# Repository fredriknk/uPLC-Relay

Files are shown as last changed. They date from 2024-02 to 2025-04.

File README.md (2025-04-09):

# μPLC-Relay
### Pcbway Sponsorship
Thanks so much to [PCBWay](https://www.pcbway.com/) who offered to assemble my first prototype batch of all three [uPLC modules](https://github.com/fredriknk/uPLC-stack). They deliver awesome quality as always, see the result for yourself below.
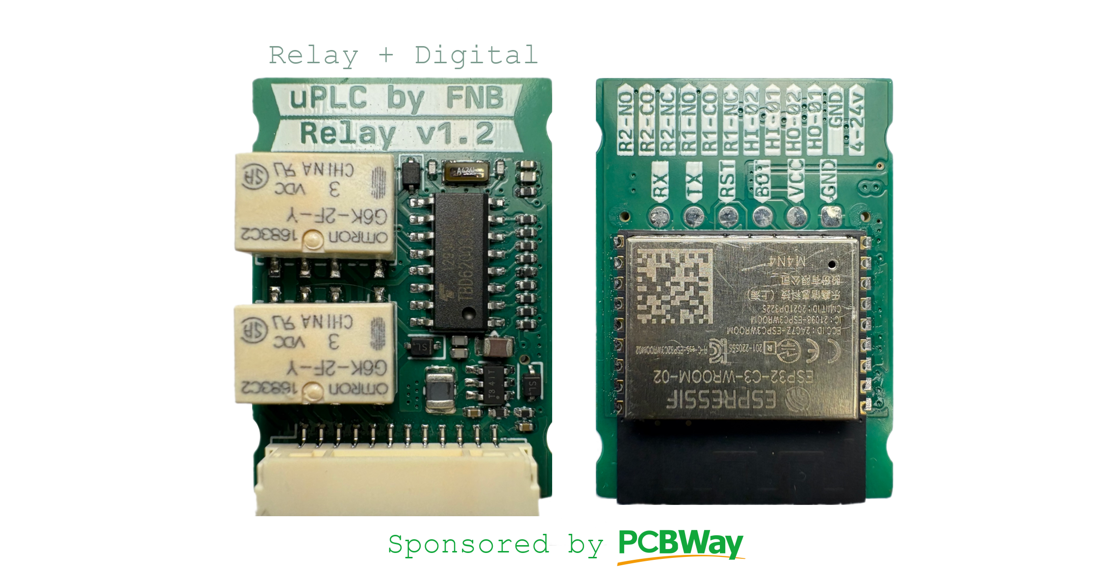
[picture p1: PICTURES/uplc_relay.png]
Front


 I now have two prototypes of the uPLC-Relay so ESP-Home integrations will come soon.

ESP micro PLC the size of a post stamp. he uPLC-relay version  has two small signal relay module utilizing an [ESP-32-C3](./DOCUMENTATION/esp-12f_product_specification_en.pdf) wifi, bluetooth module for communication and MCU, it has a 0-24V buck regulator, has two 2.5-25V inputs, two 25v, 100/50ma high speed open drain output through a [TBD062003](./DOCUMENTATION/2304140030_TOSHIBA-TBD62003AFWG_C114084.pdf) DMOS transistor array ic. And two relay outputs are capable of driving around 25V 500ma. 

Thanks to [u/PricelessToolkit/ESPClicker](https://github.com/PricelessToolkit/ESPClicker) for inspiration.

[Schematic](./DOCUMENTATION/_schematic.pdf)

[Assembly IBOM](https://htmlpreview.github.io/?https://raw.githubusercontent.com/fredriknk/uplc/main/DOCUMENTATION/ibom.html)

## Specifications
| **Parameter** | **Description** |
|---|---|
| _Input voltage_ | 3.8-24v |
| _Current_ | TBD Wifi: ##mA, Radio Off: ##mA, Deep sleep ##uA |  
| _Communication_ | 2.4ghz WIFI, Uart TTL |
| _Baudrate_ | 115200 |
| _PCB size_ | 22x31.1mm |
| _PCB info_ | 1.6mm FR4, HASL lead free, 4 layer |
| _Case size_ | XxXxXmm TBD |

## Connector

| **Label** | **GPIO**|**Description** |
|---|-----|---|
|_R2NO_ | GPIO5 | Relay 1 Normally Open |
|_R2CO_ | GPIO5  | Relay 1 COM |
|_R2NC_ | GPIO5 | Relay 1 Normally Closed |
|_R1NO_ | GPIO6 | Relay 1 Normally Open |
|_R1CO_ | GPIO6  | Relay 1 COM |
|_R1NC_ | GPIO6 | Relay 1 Normally Closed |
|_HI2_ | GPIO19 | 2.5-25v input |
|_HI1_ | GPIO18 | 2.5-25v input |
|_HO2_ | GPIO3 | 25v 50ma open drain output |
|_HO1_ | GPIO7 | 25v 100ma open drain output |
|_4-24V_ | 3V3 |4-24v |
|_GND_ | GND |  Ground  |

## PCB Pictures
PCB assembly by [PCBWay](https://www.pcbway.com/)
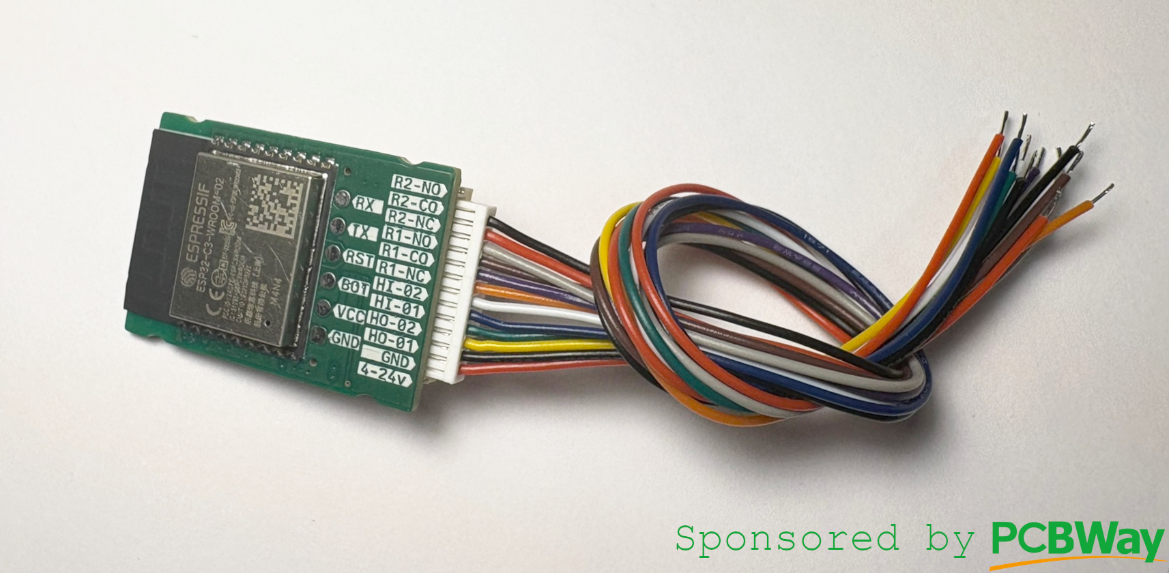
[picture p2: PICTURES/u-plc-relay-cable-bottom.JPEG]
Cable1

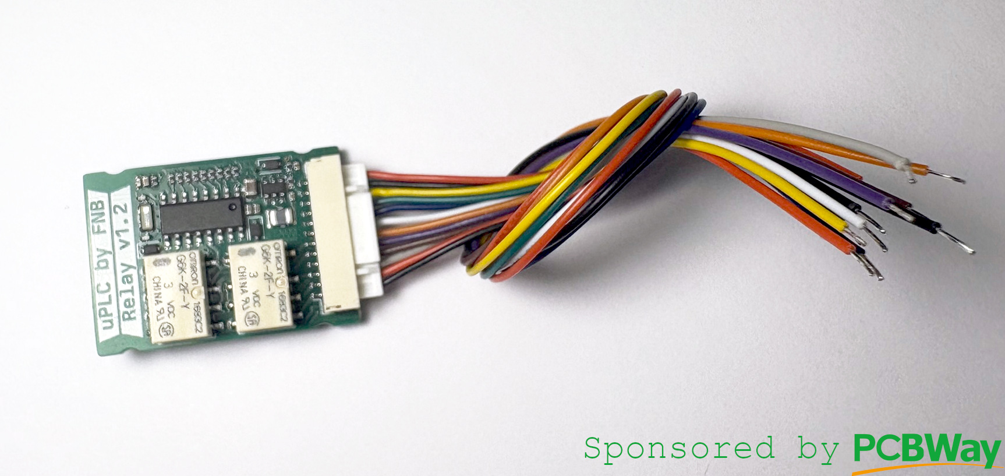
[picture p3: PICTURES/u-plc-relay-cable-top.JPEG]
Cable2

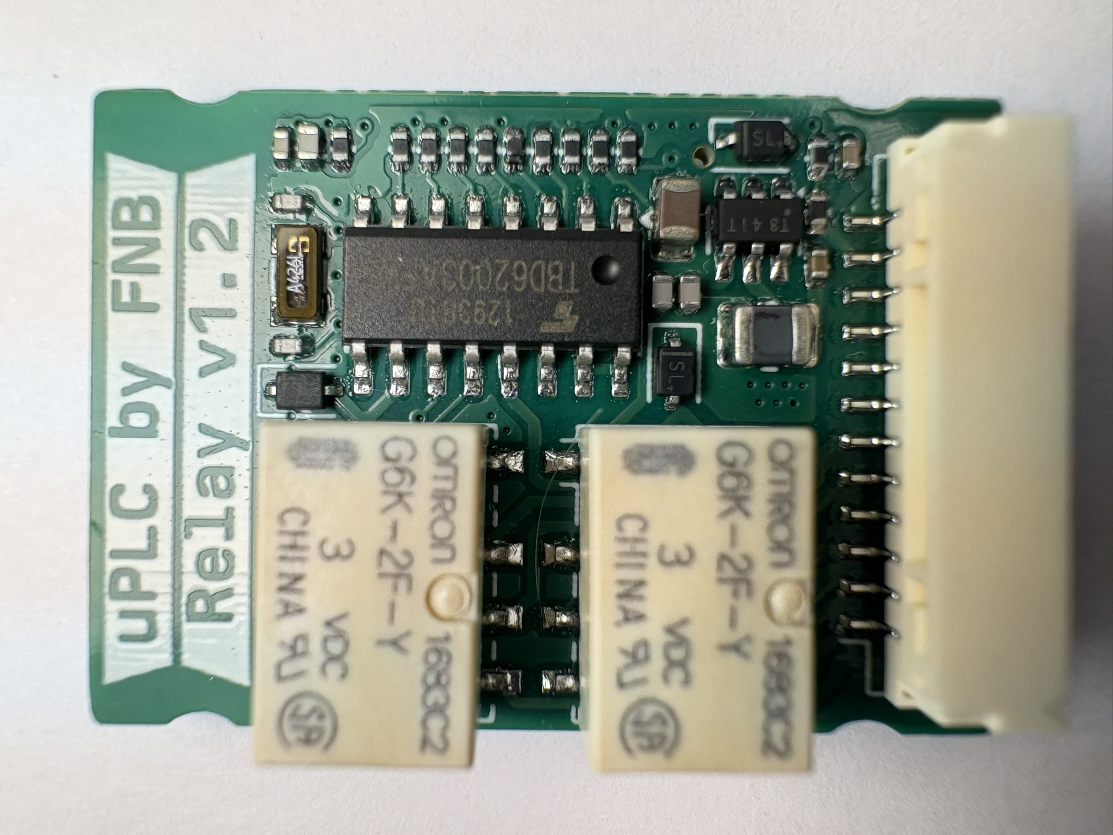
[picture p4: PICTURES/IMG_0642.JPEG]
Top

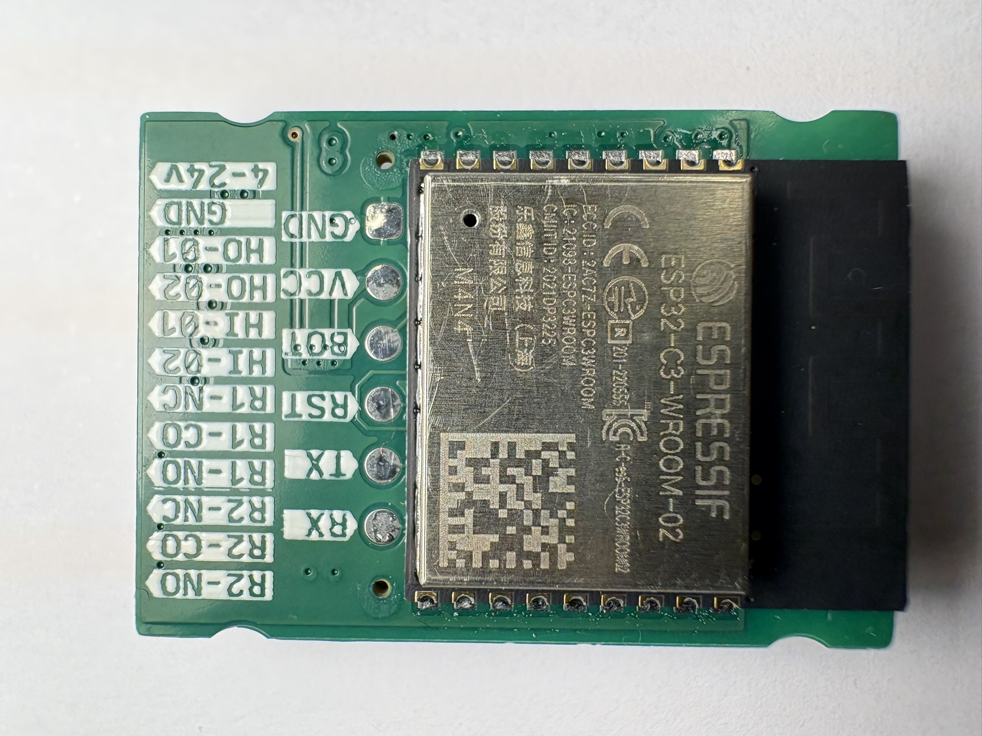
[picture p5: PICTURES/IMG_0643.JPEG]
Bottom


## Homeassistant Implementation
TODO

## FIRST PRODUCTION PROTOTYPE
TODO

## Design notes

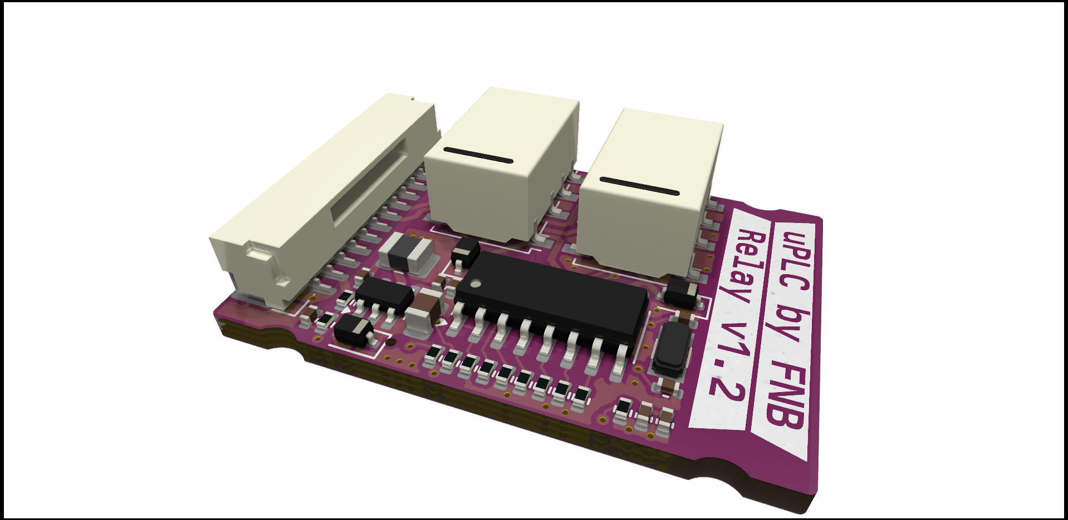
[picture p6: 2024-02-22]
PICTURES/TOP.PNG

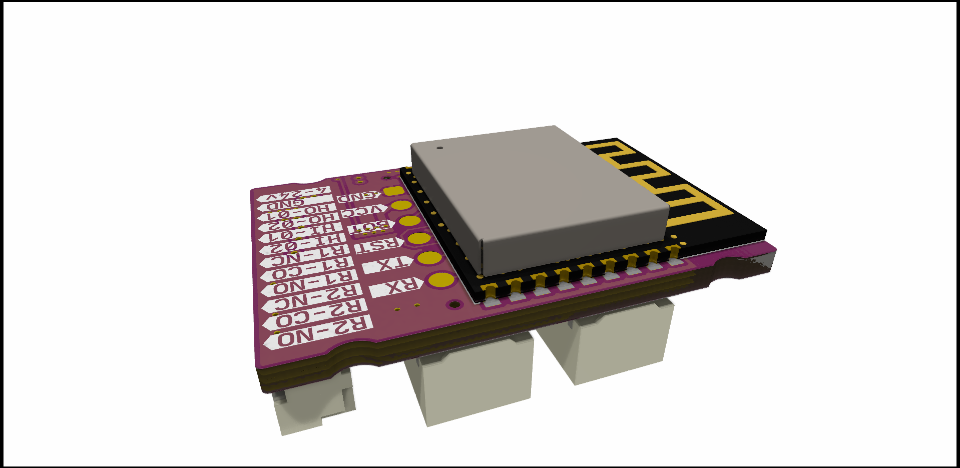
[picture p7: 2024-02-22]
PICTURES/BOTTOM.PNG

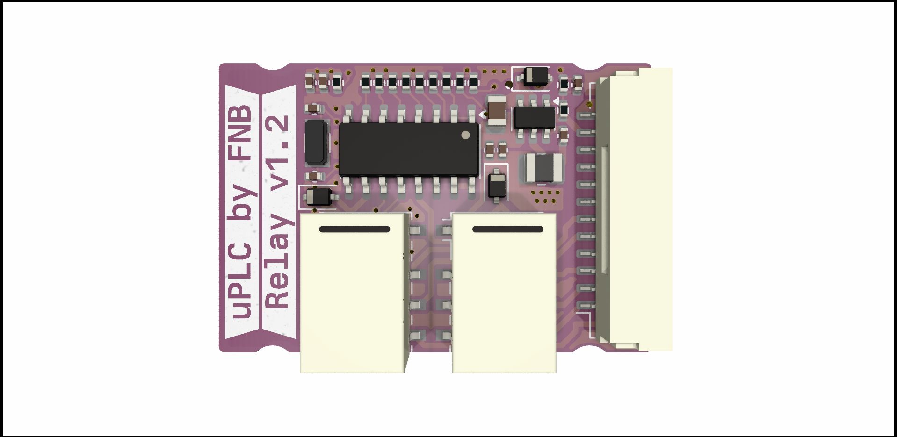
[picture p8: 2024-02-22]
PICTURES/OTOP.PNG

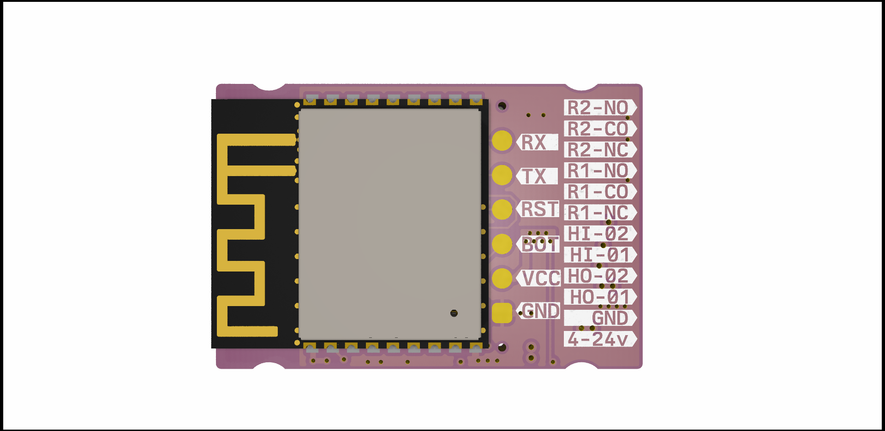
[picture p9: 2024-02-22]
PICTURES/OBOT.PNG

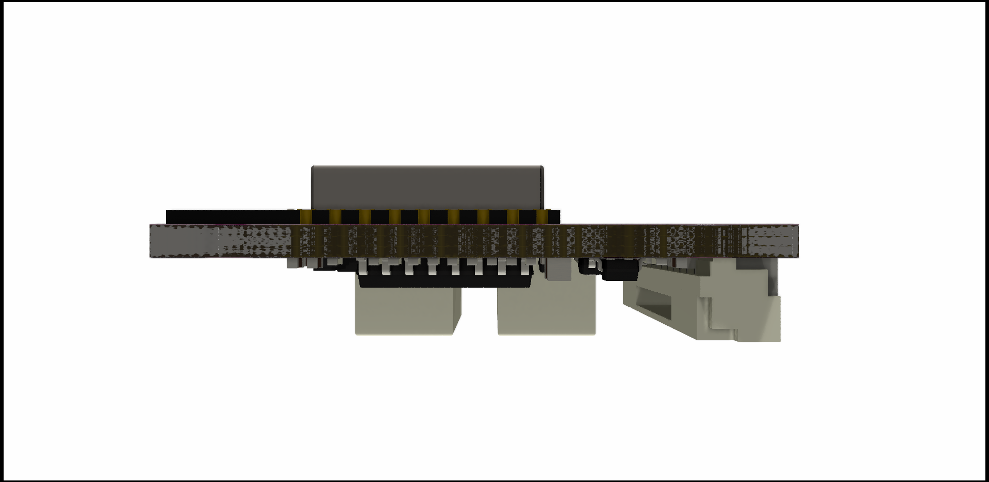
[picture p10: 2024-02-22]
PICTURES/OLEFT.png

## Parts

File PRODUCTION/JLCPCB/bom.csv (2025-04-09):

Designator | Footprint | Quantity | Value | LCSC Part #
C1, C4 | 0402 | 2 | 20pf | C1554
C11, C12, C8 | 0402 | 3 | 22uf | C415703
C2, C3, C9 | 0402 | 3 | 0.1uF | C77020
C5 | 0805 | 1 | 10uF | C162422
D1, D2, D4 | D_SOD-323 | 3 | 1N5819WS | C191023
J1 | TestPoint_Pad_1.0x1.0mm_6pad | 1 | Conn_01x06_Pin | DNP
J2 | JST_GH_SM12B-GHS-TB_1x12-1MP_P1.25mm_Horizontal | 1 | SM12B-GHS-TB(LF)(SN) | C265421
K1, K2 | Relay_DPDT_Omron_G6K-2F-Y | 2 | G6K-2F-Y | C93168
L1 | 1008 | 1 | 4.7uH | C82314
R1, R10, R11, R12, R2, R4, R5, R7, R8, R9 | 0402 | 10 | 10K | C25744
R14 | 0402 | 1 | 182k | C11481
R15 | 0402 | 1 | 62k | C137950
U1 | TSOT-23-6 | 1 | AP63201WU | C2071044
U2 | SOIC-16_3.9x9.9mm_P1.27mm | 1 | TBD62003AFWG | C114084
U3 | ESP32-C3-WROOM-02 | 1 | ESP32-C3-WROOM-02 | C2934560
Y1 | Crystal_SMD_3215-2Pin_3.2x1.5mm | 1 | 32.768khz 3215 12.5pf | C32346

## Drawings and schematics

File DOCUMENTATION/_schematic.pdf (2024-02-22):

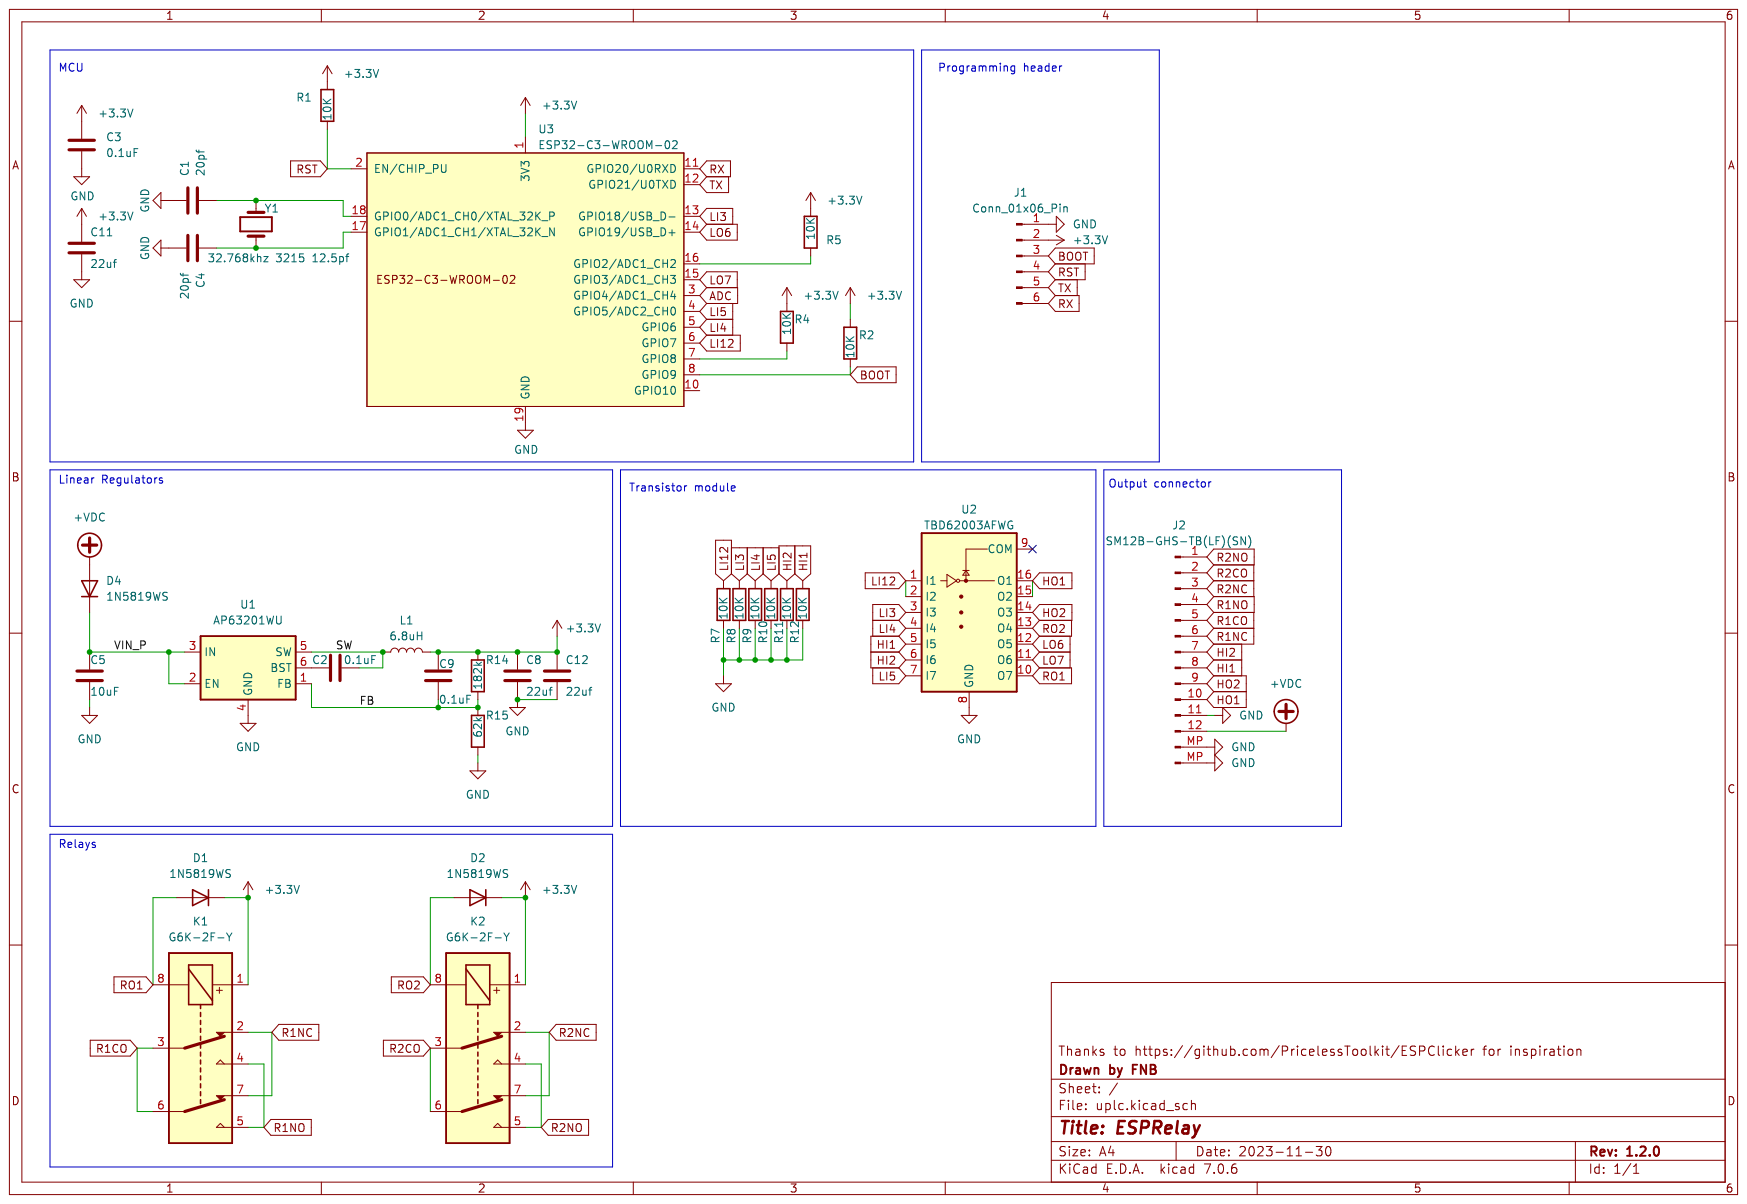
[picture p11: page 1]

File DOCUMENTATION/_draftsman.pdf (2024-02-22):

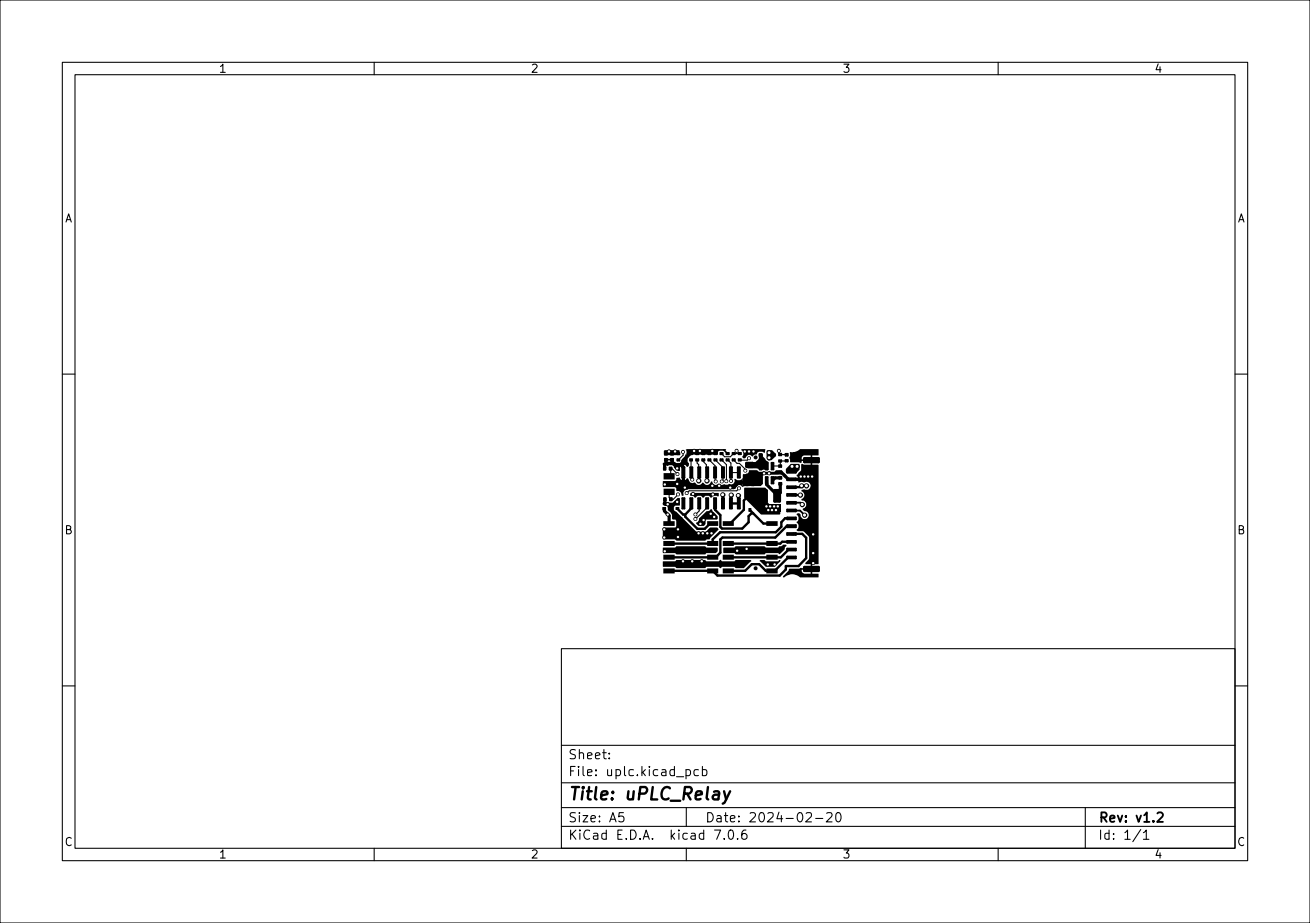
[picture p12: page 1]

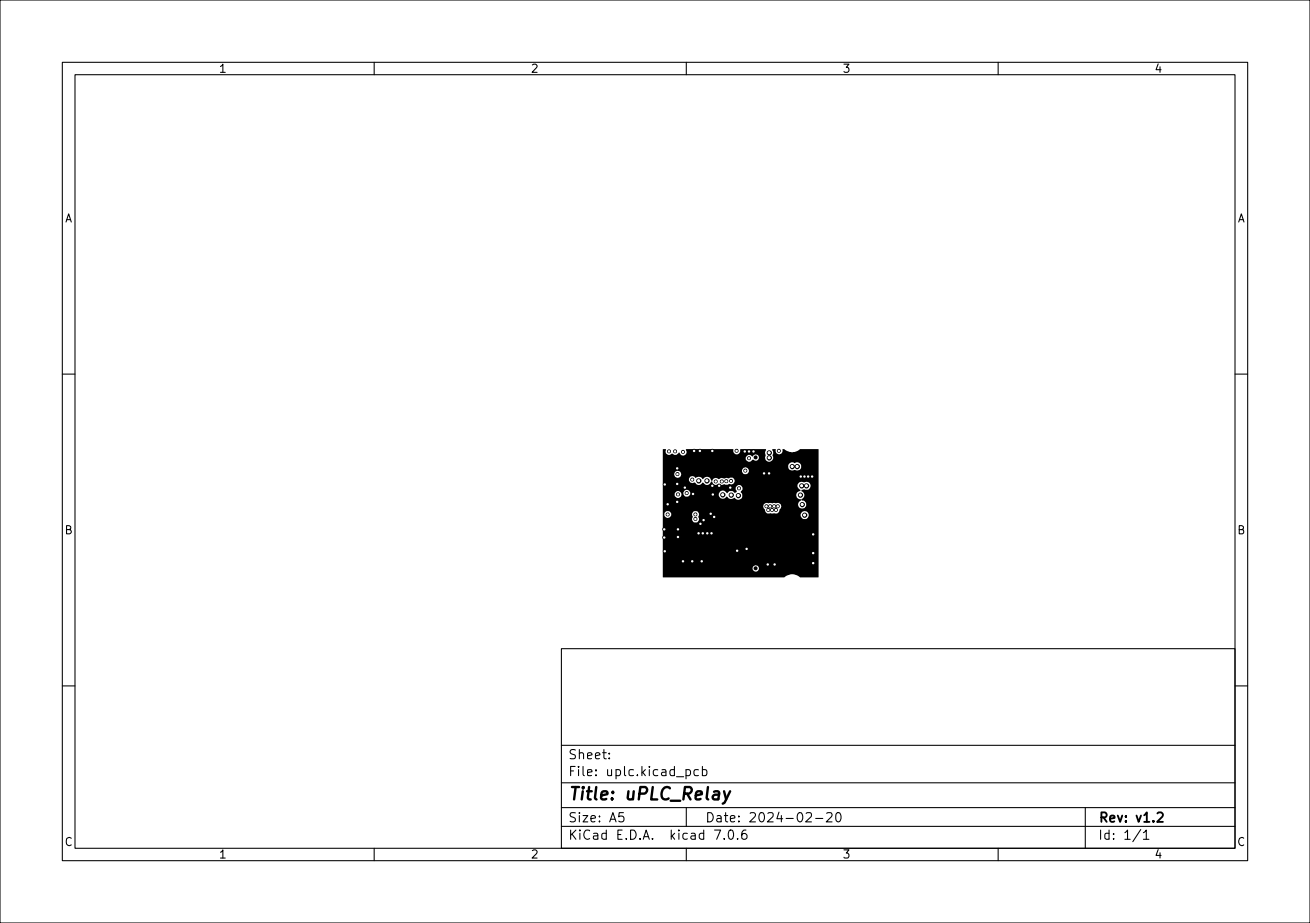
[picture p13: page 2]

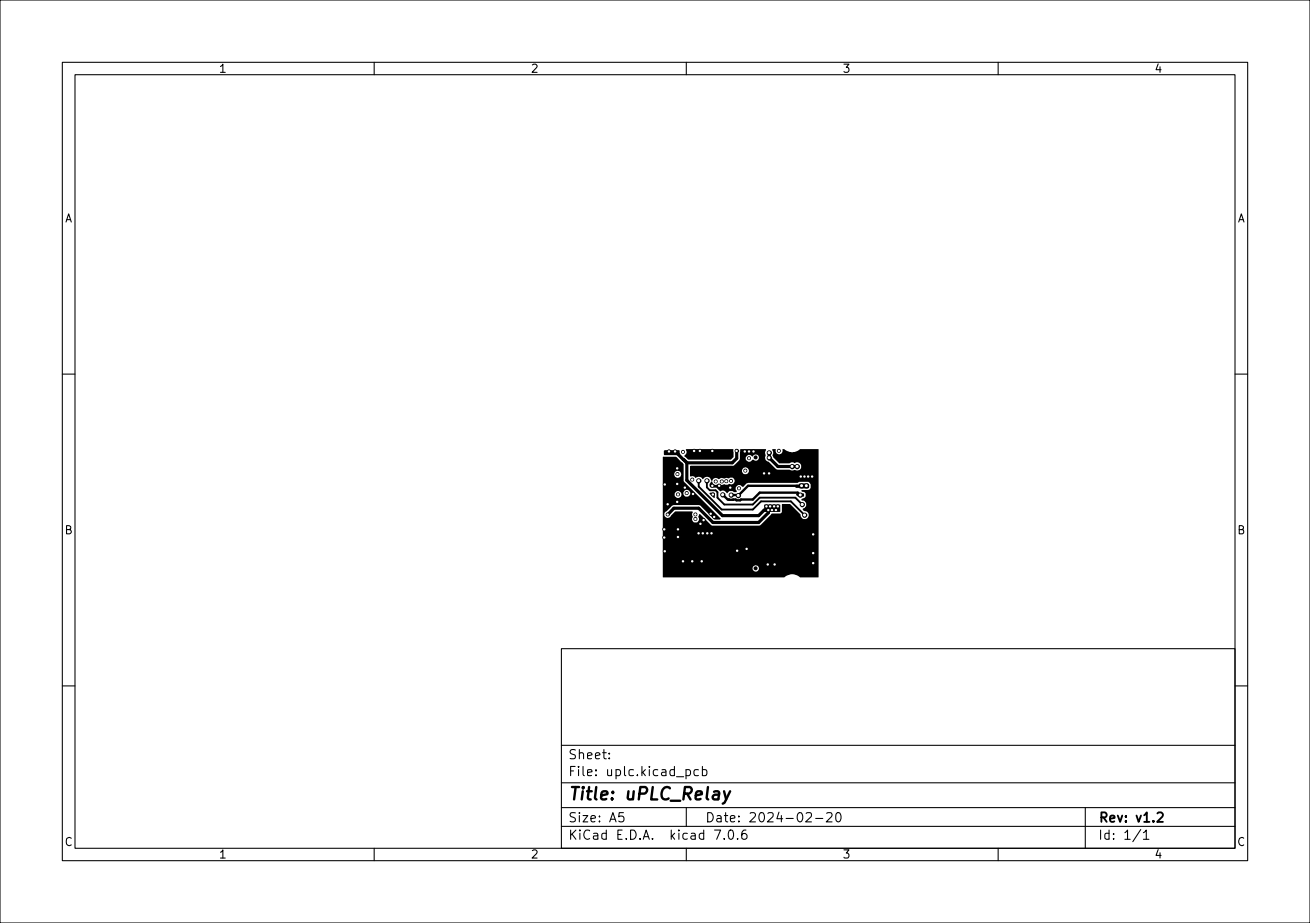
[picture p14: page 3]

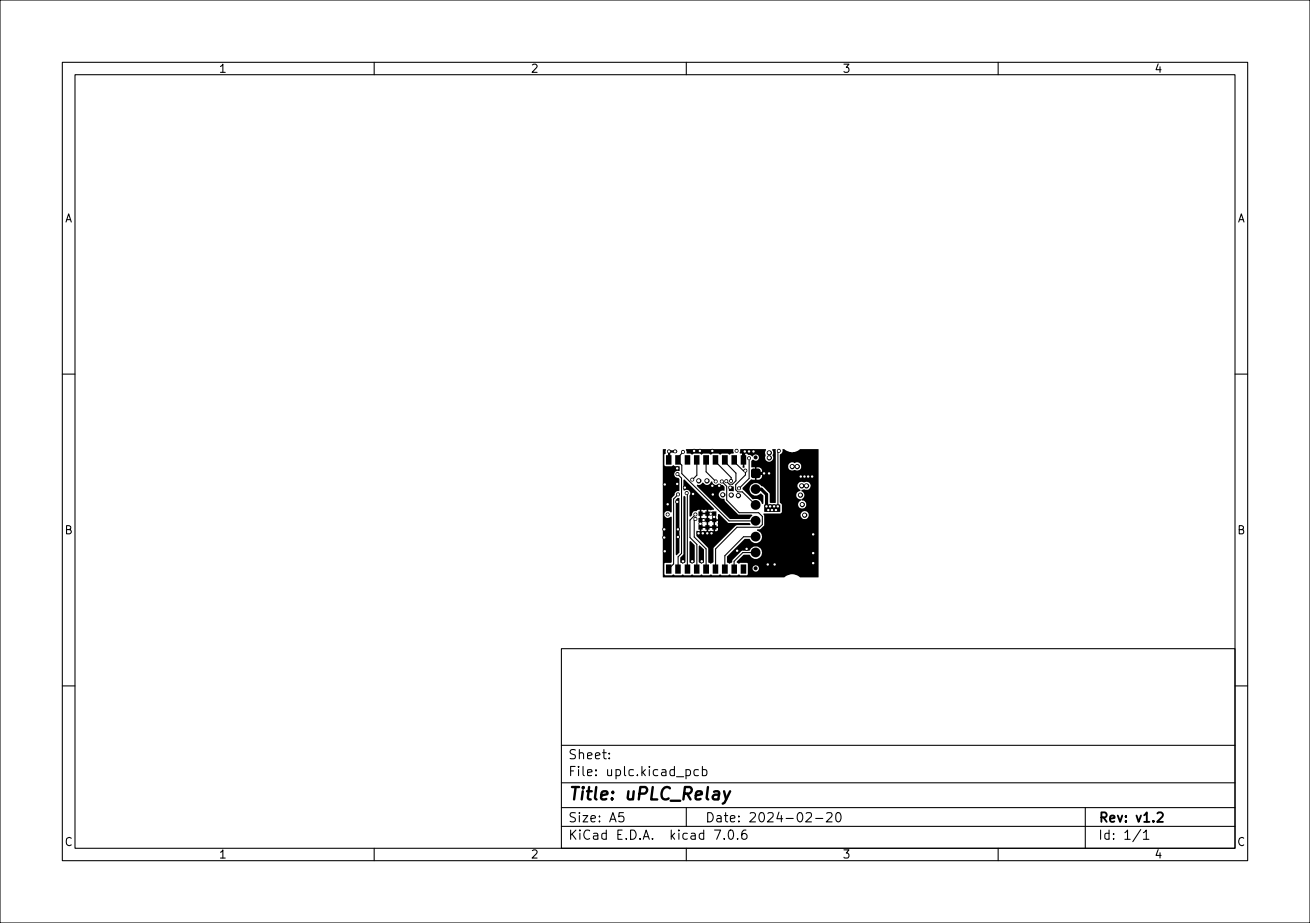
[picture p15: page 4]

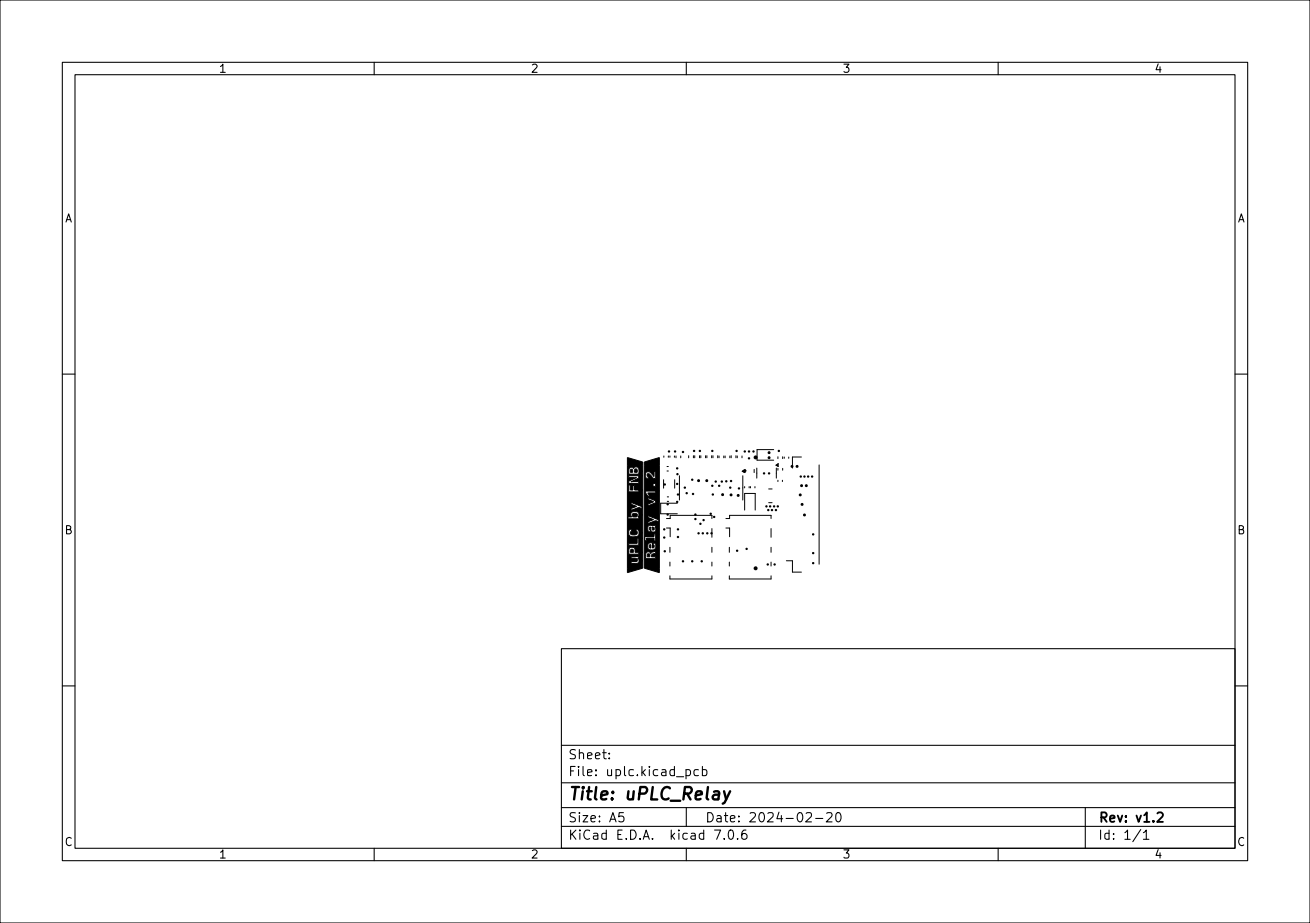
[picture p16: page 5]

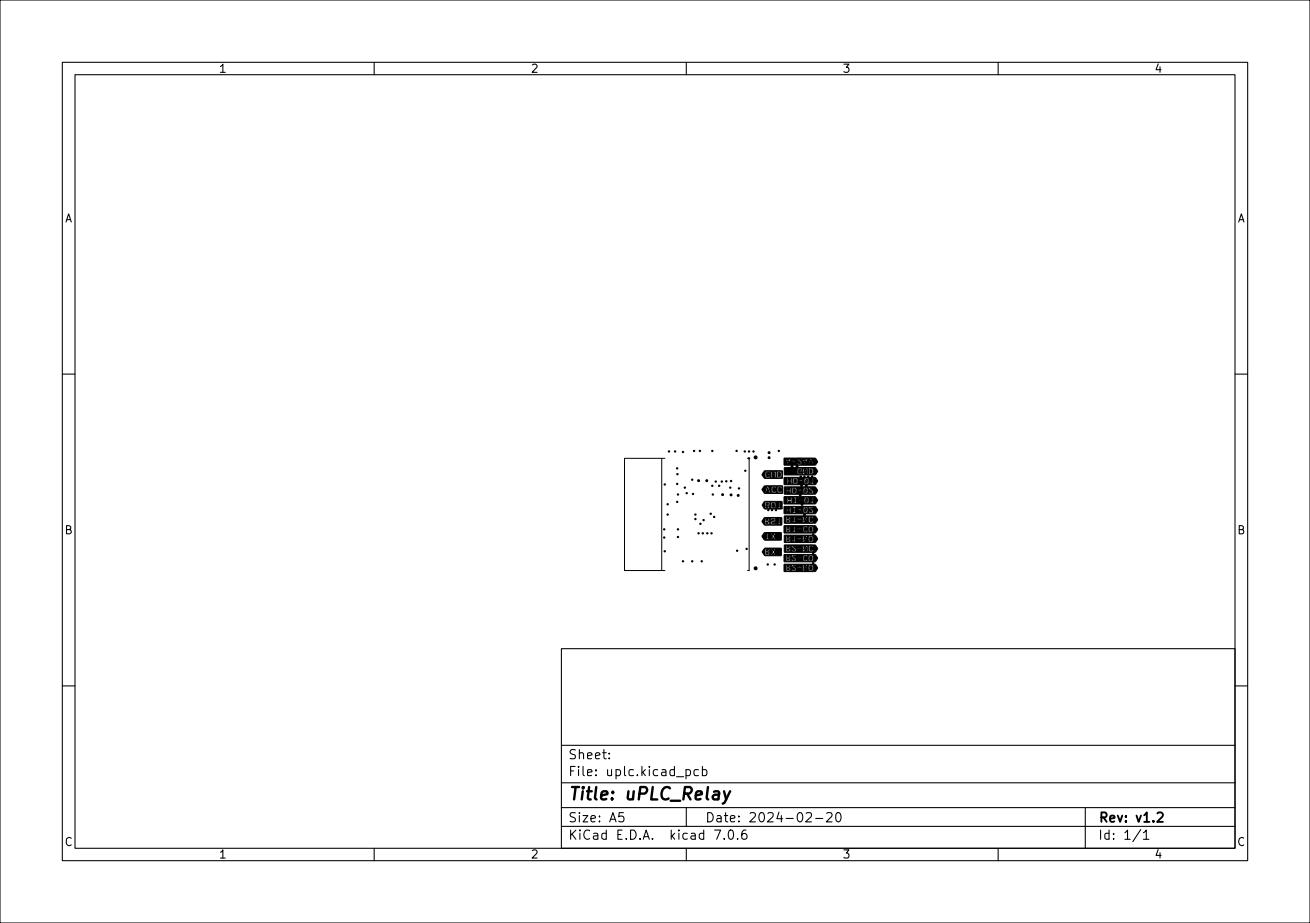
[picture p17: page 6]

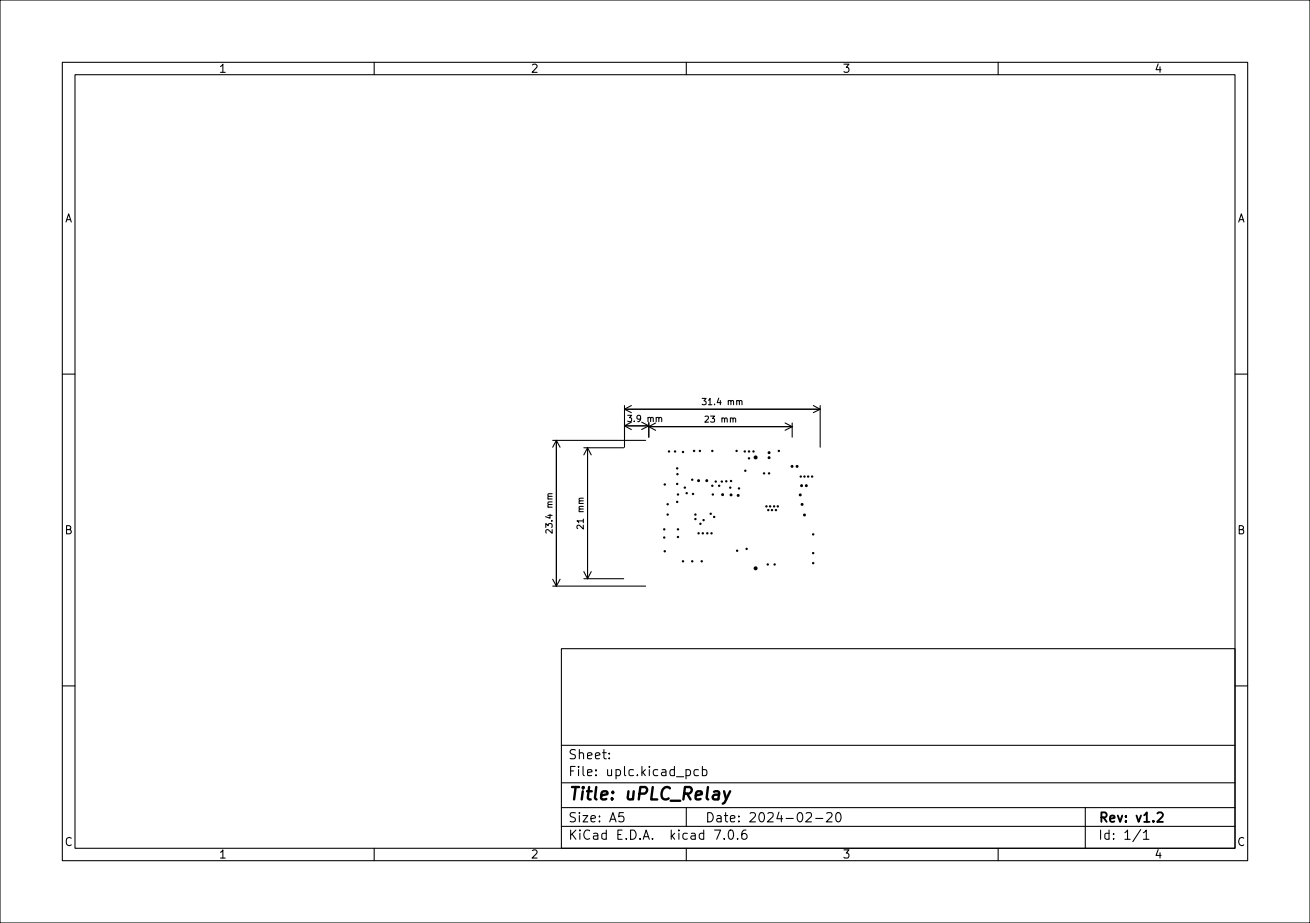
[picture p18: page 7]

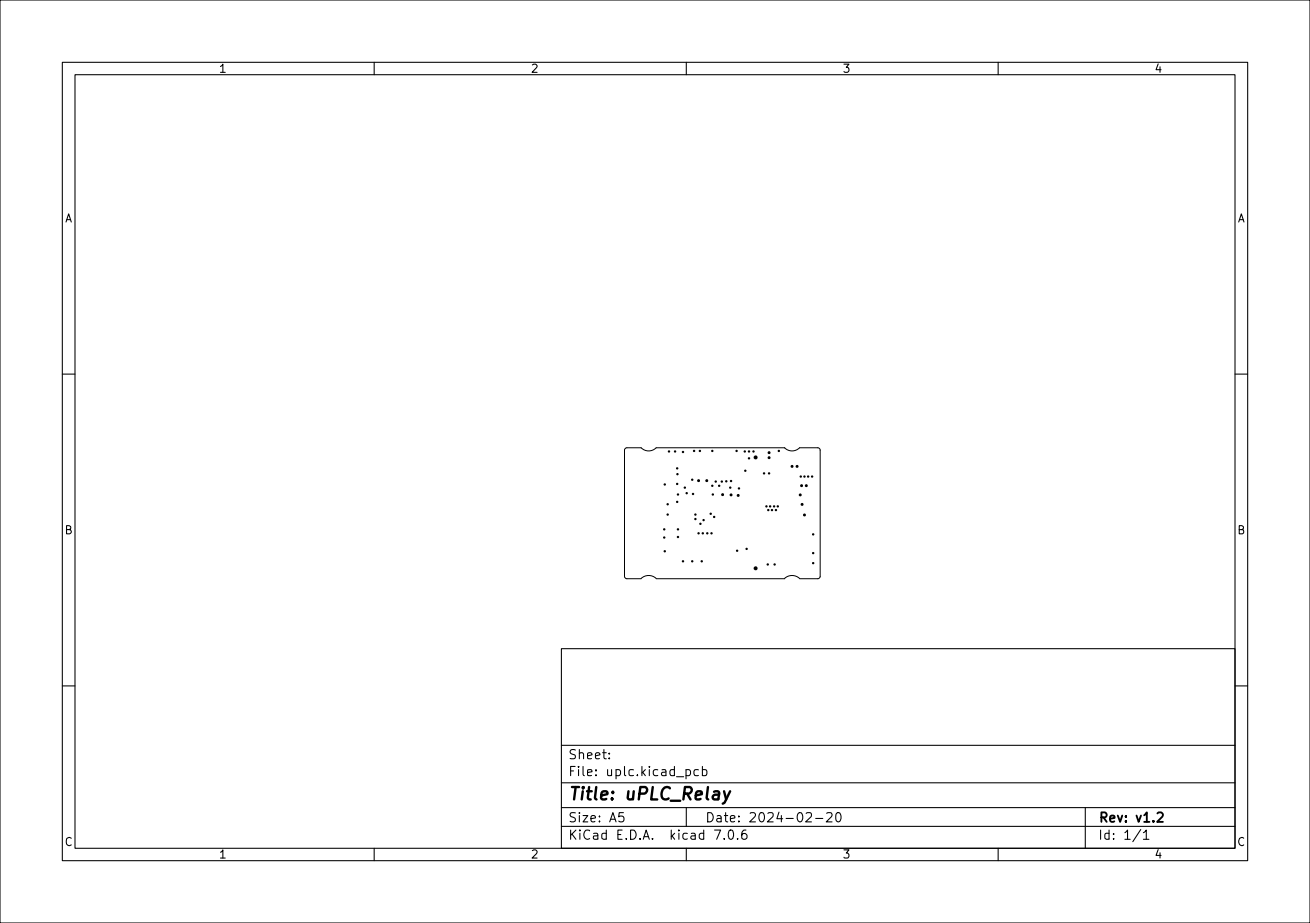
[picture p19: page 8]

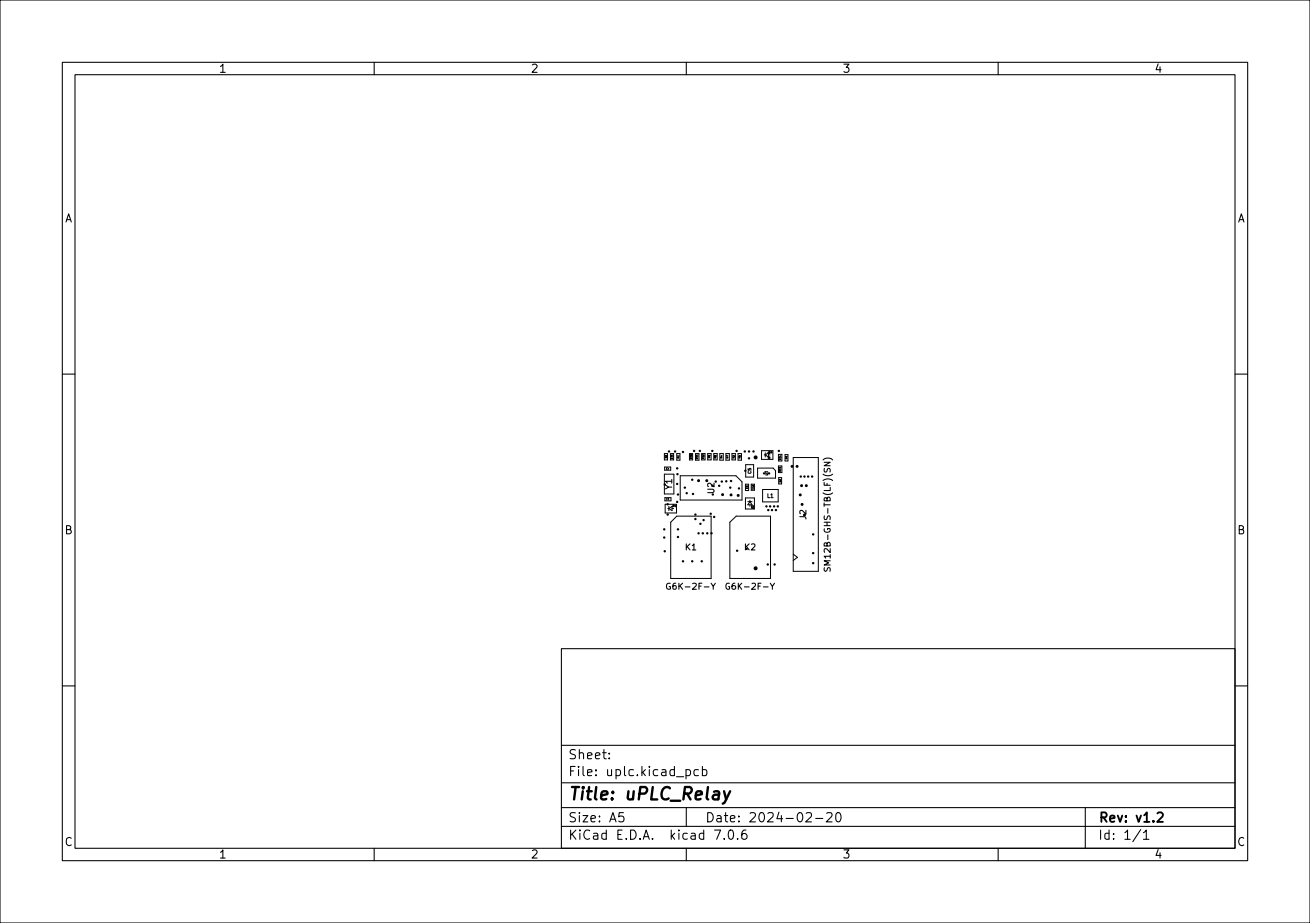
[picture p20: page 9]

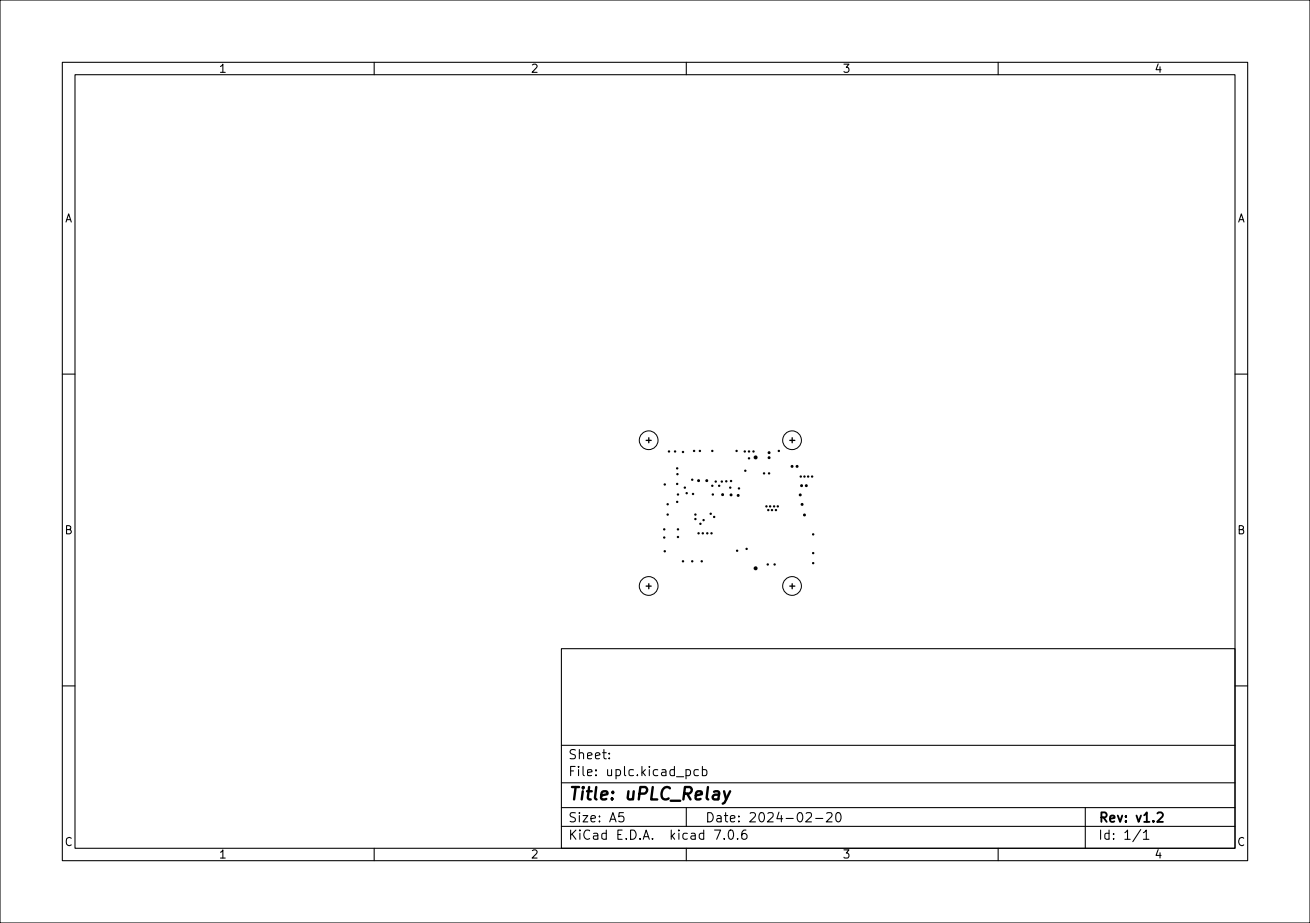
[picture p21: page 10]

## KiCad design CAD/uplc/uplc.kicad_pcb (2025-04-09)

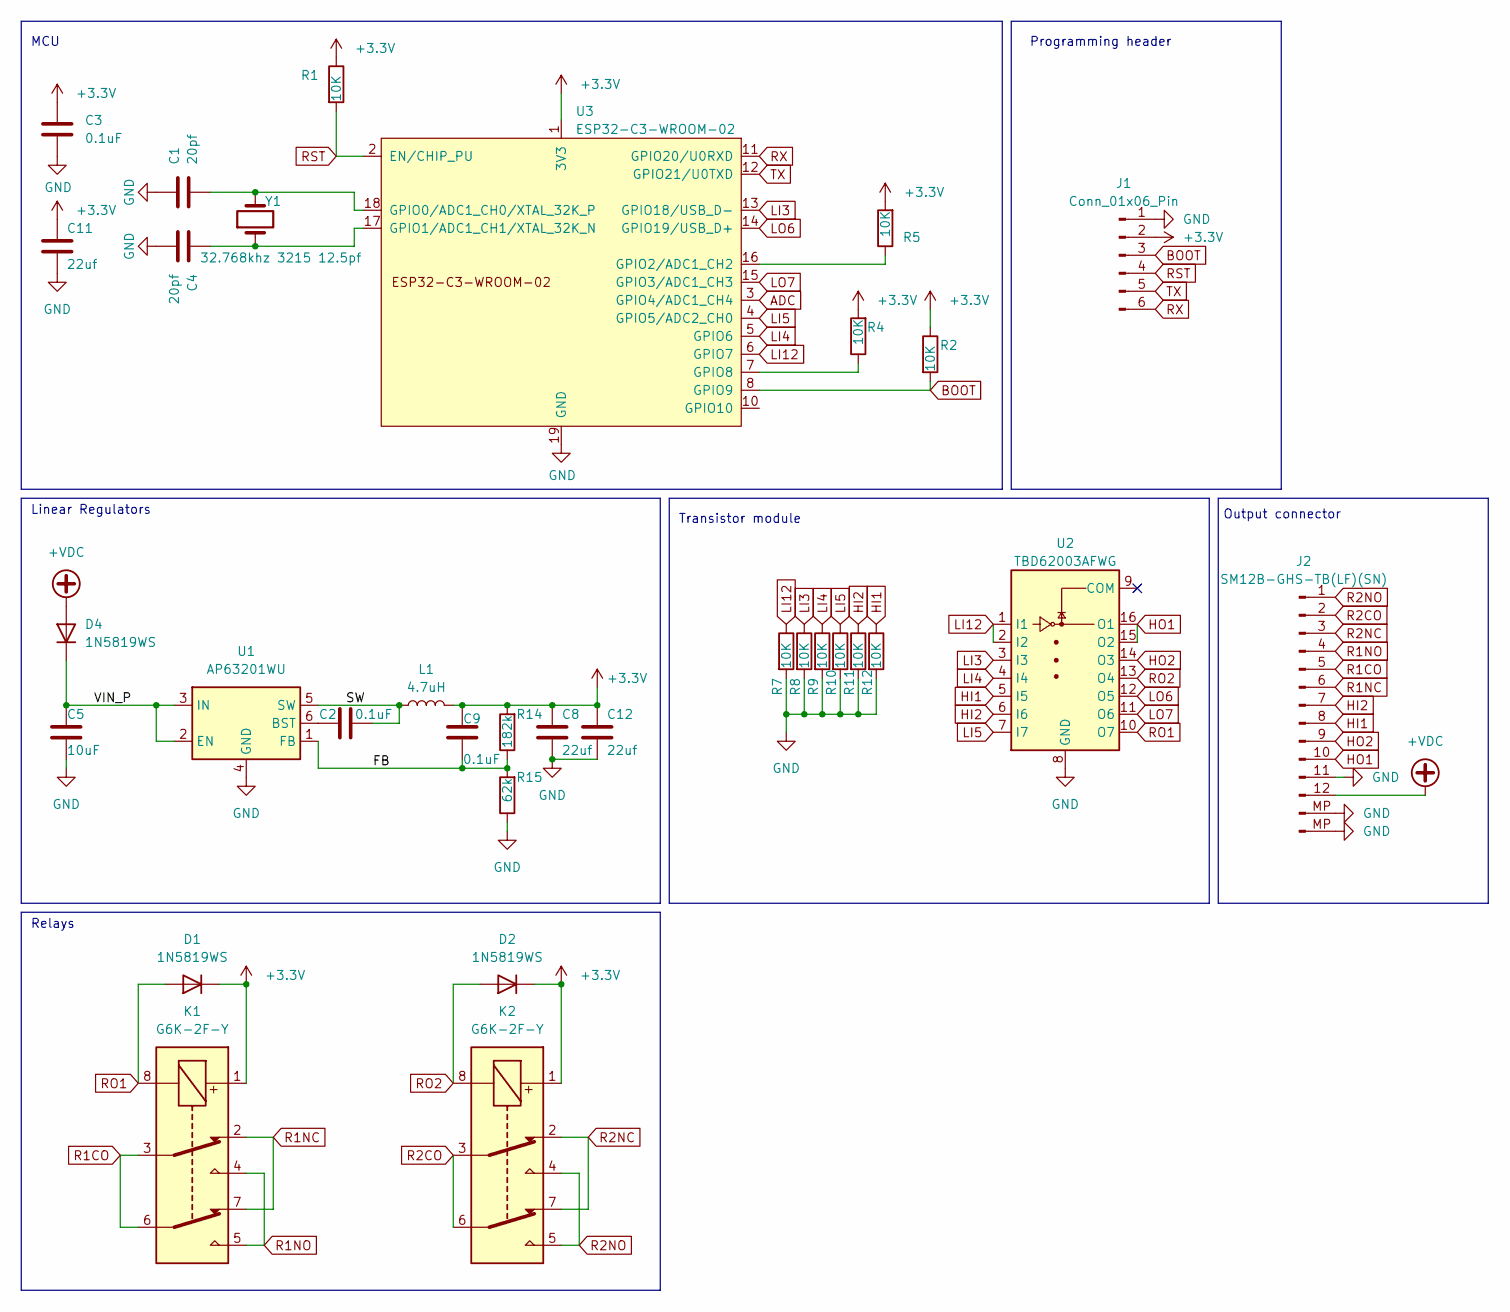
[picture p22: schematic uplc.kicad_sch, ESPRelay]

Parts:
C1, C4: 20pf; C_0402_1005Metric; MPN 0402CG200J500NT; LCSC Part # C1554
C2, C3, C9: 0.1uF; C_0402_1005Metric; MPN GRM155R71H104KE14D; LCSC Part # C77020
C5: 10uF; C_0805_2012Metric; MPN GRM21BR6YA106KE43L; LCSC Part # C162422
C8, C11, C12: 22uf; C_0402_1005Metric; MPN GRM155R60J226ME11D; LCSC Part # C415703
D1, D2, D4: 1N5819WS; D_SOD-323; MPN 1N5819WS; LCSC Part # C191023
J1: Conn_01x06_Pin; TestPoint_Pad_1.0x1.0mm_6pad; LCSC Part # DNP
J2: SM12B-GHS-TB(LF)(SN); JST_GH_SM12B-GHS-TB_1x12-1MP_P1.25mm_Horizontal; MPN SM12B-GHS-TB(LF)(SN); LCSC Part # C265421
K1, K2: G6K-2F-Y; Relay_DPDT_Omron_G6K-2F-Y; MPN G6K-2F-Y DC3; LCSC Part # C93168
L1: 4.7uH; L_1008_2520Metric; MPN LQM2HPN4R7MG0L; LCSC Part # C82314
R1, R2, R4, R5, R7, R8, R9, R10, R11, R12: 10K; R_0402_1005Metric; MPN 0402WGF1002TCE; LCSC Part # C25744
R14: 182k; R_0402_1005Metric; MPN 0402WGF1823TCE; LCSC Part # C11481
R15: 62k; R_0402_1005Metric; MPN RC0402FR-0762KL; LCSC Part # C137950
U1: AP63201WU; TSOT-23-6; MPN AP63201WU-7; LCSC Part # C2071044
U2: TBD62003AFWG; SOIC-16_3.9x9.9mm_P1.27mm; MPN TBD62003AFWG; LCSC Part # C114084
U3: ESP32-C3-WROOM-02; MPN ESP32-C3-WROOM-02-N4; LCSC Part # C2934560
Y1: 32.768khz 3215 12.5pf; Crystal_SMD_3215-2Pin_3.2x1.5mm; MPN Q13FC13500004; LCSC Part # C32346

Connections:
+3.3V: C3.1, C8.1, C9.1, C11.1, C12.1, D1.1 (K), D2.1 (K), J1.2, K1.1, K2.1, L1.2, R1.1, R2.1, R4.2, R5.2, R14.2, U3.1 (3V3)
+VDC: D4.2 (A), J2.12
/FB: C9.2, R14.1, R15.2, U1.1 (FB)
/SW: C2.1, L1.1, U1.5 (SW)
/VIN_P: C5.1, D4.1 (K), U1.2 (EN), U1.3 (IN)
ADC: U3.3 (GPIO4/ADC1_CH4)
BOOT: J1.3, R2.2, U3.8 (GPIO9)
GND: C1.1, C3.2, C4.2, C5.2, C8.2, C11.2, C12.2, J1.1, J2.11, J2.MP (Pin_13), R7.2, R8.2, R9.2, R10.2, R11.2, R12.2, R15.1, U1.4 (GND), U2.8 (GND), U3.9 (GND), U3.19 (GND)
HI1: J2.8, R12.1, U2.5 (I5)
HI2: J2.7, R11.1, U2.6 (I6)
HO1: J2.10, U2.15 (O2), U2.16 (O1)
HO2: J2.9, U2.14 (O3)
LI3: R8.1, U2.3 (I3), U3.13 (GPIO18/USB_D-)
LI4: R9.1, U2.4 (I4), U3.5 (GPIO6)
LI5: R10.1, U2.7 (I7), U3.4 (GPIO5/ADC2_CH0)
LI12: R7.1, U2.1 (I1), U2.2 (I2), U3.6 (GPIO7)
LO6: U2.12 (O5), U3.14 (GPIO19/USB_D+)
LO7: U2.11 (O6), U3.15 (GPIO3/ADC1_CH3)
unnamed: C2.2, U1.6 (BST)
unnamed: C1.2, U3.18 (GPIO0/ADC1_CH0/XTAL_32K_P), Y1.2
unnamed: C4.1, U3.17 (GPIO1/ADC1_CH1/XTAL_32K_N), Y1.1
unnamed: R5.1, U3.16 (GPIO2/ADC1_CH2)
unnamed: R4.1, U3.7 (GPIO8)
R1CO: J2.5, K1.3, K1.6
R1NC: J2.6, K1.2, K1.7
R1NO: J2.4, K1.4, K1.5
R2CO: J2.2, K2.3, K2.6
R2NC: J2.3, K2.2, K2.7
R2NO: J2.1, K2.4, K2.5
RO1: D1.2 (A), K1.8, U2.10 (O7)
RO2: D2.2 (A), K2.8, U2.13 (O4)
RST: J1.4, R1.2, U3.2 (EN/CHIP_PU)
RX: J1.6, U3.11 (GPIO20/U0RXD)
TX: J1.5, U3.12 (GPIO21/U0TXD)

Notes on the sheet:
Transistor module
Linear Regulators
MCU
Output connector
Programming header
Relays

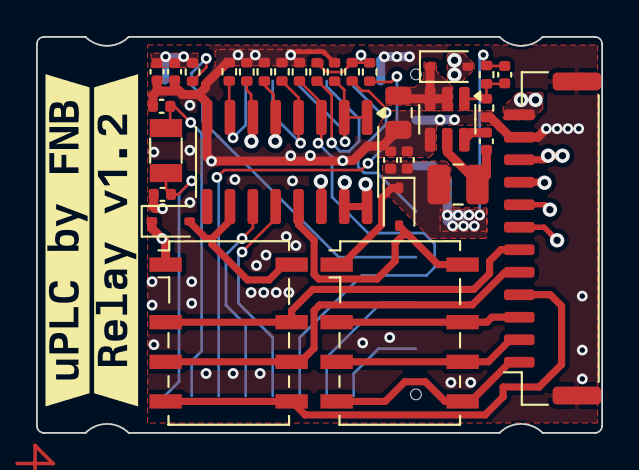
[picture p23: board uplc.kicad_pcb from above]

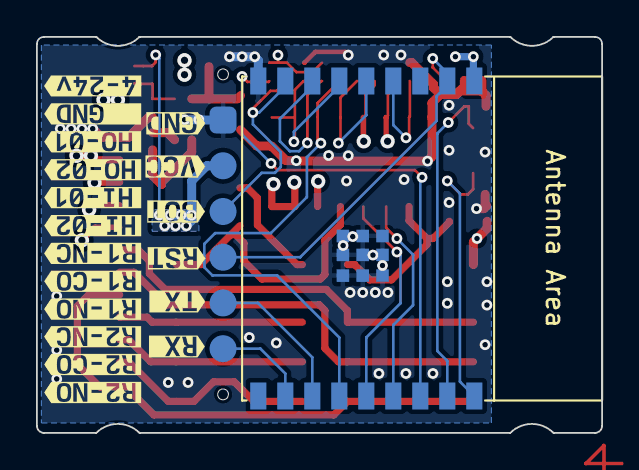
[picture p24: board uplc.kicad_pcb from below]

Board: 4 copper layers, 31.4 x 22.0 mm, 53 parts (20 on the bottom side), 33 nets.

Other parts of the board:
kibuzzard-65D6FF37: G***; kibuzzard-65D6FF37
kibuzzard-65D361A7: G***; kibuzzard-65D361A7
kibuzzard-65D361B0: G***; kibuzzard-65D361B0
kibuzzard-65D361D3: G***; kibuzzard-65D361D3
kibuzzard-65D361E1: G***; kibuzzard-65D361E1
kibuzzard-65D361E9: G***; kibuzzard-65D361E9
kibuzzard-65D361F2: G***; kibuzzard-65D361F2
kibuzzard-65D361FD: G***; kibuzzard-65D361FD
kibuzzard-65D460A0: G***; kibuzzard-65D460A0
kibuzzard-65D3616E: G***; kibuzzard-65D3616E
kibuzzard-65D3619D: G***; kibuzzard-65D3619D
kibuzzard-65D3620E: G***; kibuzzard-65D3620E
kibuzzard-65D7176D: G***; kibuzzard-65D7176D
kibuzzard-65D7177B: G***; kibuzzard-65D7177B
kibuzzard-65D36177: G***; kibuzzard-65D36177
kibuzzard-65D36206: G***; kibuzzard-65D36206
kibuzzard-65D46022: G***; kibuzzard-65D46022
kibuzzard-65D46066: G***; kibuzzard-65D46066
kibuzzard-65D49092: G***; kibuzzard-65D49092
kibuzzard-65D71774: G***; kibuzzard-65D71774

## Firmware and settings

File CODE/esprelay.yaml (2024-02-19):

substitutions:
  name: "ESPRelay-1"
  friendly_name: "ESPRelay-1"

esphome:
  name: esphome-web-172b99
  friendly_name: ESPRELAY-1

esp8266:
  board: d1_mini
  early_pin_init: false

# Enable logging
logger:

# Enable Home Assistant API
api:
  encryption:
    key: "CHANGEME"

ota:


wifi:
  ssid: !secret wifi_ssid
  password: !secret wifi_password
  fast_connect: true
  # Enable fallback hotspot (captive portal) in case wifi connection fails
  ap:
    ssid: "Esphome-Web-172B99"
    password: "CHANGEME"

captive_portal:

sensor:

- platform: adc
  pin: A0
  name: "${friendly_name} Light"
  update_interval: 5s

- platform: uptime
  name: "${friendly_name} Uptime"
  id: uptime_seconds

- platform: wifi_signal
  name: "${friendly_name} WiFi Signal"

binary_sensor:
  - platform: status
    name: "${friendly_name} Status"

  - platform: gpio
    pin:
      number: 0
      inverted: true
      mode:
        input: true
    filters:
      - delayed_on: 10ms
    name: "${friendly_name} BUTTON"

  - platform: gpio
    pin:
      number: 4
      inverted: true
      mode:
        input: true
        pullup: true
    filters:
      - delayed_on: 10ms
    name: "${friendly_name} INPUT1"

  - platform: gpio
    pin:
      number: 5
      inverted: true
      mode:
        input: true
        pullup: true
    filters:
      - delayed_on: 10ms
    name: "${friendly_name} INPUT2"

switch:
  - platform: restart
    name: "${friendly_name} restart"


##########################################
  - platform: gpio
    pin: 12
    id: Relay1
    name: "${friendly_name} Relay1"
    icon: "mdi:switch"
    restore_mode: ALWAYS_OFF
##########################################
  - platform: gpio
    pin: 14
    id: Relay2
    name: "${friendly_name} Relay2"
    icon: "mdi:switch"
    restore_mode: ALWAYS_OFF
########################################
  - platform: gpio
    pin: 15
    id: Relay3
    name: "${friendly_name} Relay3"
    icon: "mdi:switch"
    restore_mode: ALWAYS_OFF
########################################
  - platform: gpio
    id: LS1
    name: "${friendly_name} LS1"
    icon: "mdi:switch"
    restore_mode: ALWAYS_OFF
    pin: 13
##########################################
  - platform: gpio
    pin: 
      number: 2
      inverted: true
    id: Ledpin
    name: "${friendly_name} LED"
    icon: "mdi:switch"
    restore_mode: ALWAYS_OFF

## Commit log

2024-02-19 Hardfork esprelay
    [bom.csv, designators.csv, positions.csv]
2024-02-19 RTC insert
    [bom.csv, designators.csv, positions.csv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]
2024-02-19 Pin Rearangement
    [uplc.kicad_sch]
2024-02-20 Rev 1.0
    [bom.csv, designators.csv, esprelay.kicad_pcb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]
2024-02-21 Value updates
    [bom.csv, uplc.kicad_pcb, uplc.kicad_sch]
2024-02-21 rev 1.1
    [uplc.kicad_pcb, uplc.kicad_sch]
2024-02-22 Rev 1.2
    [uplc.kicad_pcb, uplc.kicad_sch]
2024-02-22 Production push rev 1.2
    [bom.csv, designators.csv, positions.csv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]
2024-02-22 Update rev nr
    [bom.csv, designators.csv, positions.csv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]
2024-10-14 Panelization changes
    [uplc.kicad_pcb, uplc.kicad_sch]
